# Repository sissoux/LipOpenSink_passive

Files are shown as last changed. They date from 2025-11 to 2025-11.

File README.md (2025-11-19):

# E-DDY

Smart passive load add-on for the ToolkitRC M8D charger. Bridges Channel 1 → Channel 2 into an external 3.3 Ω / 300 W resistor for higher discharge power. An onboard RP2040 supervises temperature, drives a 12 V fan (from the M8D’s USB-C PD), and cuts the load on error/thresholds. A simple USB configuration tool lets you tune behavior and monitor telemetry.

> Safety note: Ensure adequate cooling. Firmware enforces "no fan → no load": when the fan tach (GP12) shows no pulses while the fan should be running, the load is forced OFF and the LED blinks. Temperature and VIN thresholds also protect the load.

---

## Features

- Temperature monitoring with configurable filtering and calibration
- Fan control via LUT (temperature → PWM duty) with hysteresis and smooth ramping
- Load cutoff on over-temperature, with LED indicator
- Optional VIN-based load cutoff with hysteresis (configurable)
- Fan presence check via tach on GP12; interlock enforces "no fan → no load" with blinking LED
- Broken temperature sensor safety: if NTC (high-side) reads unrealistically low (< -25°C), the load is opened
- Settings persistence in RP2040 NVM (CRC-checked, adaptive to capacity)
- USB configuration tool (CDC/serial) to edit parameters and view telemetry

---

## Repository structure

```text
.
├── firmware/               # RP2040 (CircuitPython)
│   ├── boot.py             # Optional: expose dual CDC ports early
│   ├── code.py             # Firmware entry point
│   ├── LUTs.py             # Lookup tables (ADC→Temp, Temp→Duty)
│   └── uart_cmd.py         # Dual-CDC + ASCII command server
│
├── config_tool/            # PC configuration utility (Python 3)
│   ├── config_gui.py       # Tkinter GUI: params, telemetry, calibration
│   └── requirements.txt    # Dependencies for the GUI
│
├── PCB/                    # Hardware design (Altium) + outputs
│   ├── SRC/                # Schematics, PCB project/files
│   ├── FAB/                # Gerbers, drill, fabrication outputs
│   ├── ASSY/               # BOM, pick-and-place
│   └── 3D/                 # STEP and 3D PDF
│
├── tools/                  # Host-side helpers
│   ├── Temperature Log Plotter.py  # Plot CSV telemetry (example)
│   └── reports/            # Example logs and plots
│
└── README.md
```

Note: Hardware CAD and 3D outputs are provided under the license below.

---

## Quick start

### Hardware

1. Assemble the module with the 3.3 Ω / 300 W resistor, fan, and RP2040 board.
2. Power the fan from the M8D USB-C (12 V PD) as designed in your hardware.
3. Wire the module in the M8D’s discharge bridge path (CH1 → resistor → CH2).

### Firmware (RP2040)

1. Install CircuitPython for your RP2040 board.
2. Copy `firmware/code.py` and `firmware/LUTs.py` to the CIRCUITPY drive.
	- Optional: also copy `firmware/boot.py` to expose both CDC endpoints on boot.
3. Power-cycle the board; defaults will run immediately (telemetry is OFF by default).
4. Optionally adjust settings with the configuration tool and save to NVM.

### Configuration tool (PC)

Install dependencies (Windows PowerShell example):

```
pip install -r config_tool/requirements.txt
```

Launch the GUI:

```
python config_tool/config_gui.py
```

In the GUI:

- Select the serial port (CDC/COM) and Auto-Connect or Connect.
- Use Refresh to load current parameters; adjust values and Apply; Save to flash when satisfied.
- Live telemetry (CSV mode) is shown in the panel; you can set manual fan duty for testing.
- Use Start Rec to log Temperature (°C) and fan duty (%) every 1 s; click Stop to choose where to save the CSV.

Currently, the GUI focuses on parameters, telemetry, and basic calibration. LUT editing (upload/download) is supported by the device’s ASCII protocol but not yet exposed in the GUI.

---

## What you can configure

- Thermal & safety: cutoff temperature, hysteresis, ADC filtering
- Fan behavior: minimum duty, ramp time/step, temperature → duty LUT (device-side)
- Calibration: VIN and temperature channels (a·x + b) — temperature offset/slope act on °C
- Telemetry: rate (ms) and format (CSV or human-readable)
- VIN-based load cutoff: `LOAD_TRIP_V` and `HYST_V`

---

## Updating LUTs (advanced)

LUTs can be retrieved and updated via the serial ASCII protocol implemented in `uart_cmd.py`:

- GET/SET LUT TEMP_TO_DUTY
- GET/SET LUT ADC_TO_TEMP_5C

Use a serial terminal to issue HELP for the exact command shapes (BEGIN/END block mode with indexed rows). GUI support for LUT editing is planned but not yet available.

---

## Typical workflow

1. Power the module from the M8D (USB-C 12 V) and flash the firmware.
2. Verify the fan ramps according to temperature requirements.
3. Connect the configuration tool; adjust calibration, thresholds, and telemetry rate.
4. Save to flash, run a controlled discharge, and iterate based on telemetry.

---

## License

Licensed under CERN-OHL-S-2.0

© 2025 ADSTech [e-ddy]

https://ohwr.org/licences/

---

## Versioning & Breaking Changes

The configuration GUI performs a firmware version check on connect. Minimum supported firmware: **v1.3.1**.

| Area | Change | Firmware Version | GUI Impact |
|---|---|---|---|
| Safety | Added broken sensor low-temp safety (`BROKEN_TEMP_CUTOFF_C`, opens load if temp < -25°C) | 1.3.1 | Automatically enforced; no GUI control |
| Voltage Policy | Independent VIN cutoff with hysteresis (`LOAD_TRIP_V`, `HYST_V`) | 1.3.1 | Editable in GUI |
| Voltage Policy | Added VIN cutoff bypass parameter `BYPASS_VIN_CUTOFF` (1=bypass enabled) | 1.3.1 | Checkbox in GUI; hidden/disabled if firmware < 1.3.1 |
| Telemetry | CSV telemetry expanded (includes load state, mode) | 1.3.1 | Parsed by GUI recorder |
| GUI Logging | 1 Hz recording of Temperature & Fan Duty to CSV | (host feature) | Available regardless of firmware (needs CSV telemetry enabled) |
| Fan Safety | Fan tach interlock & LED blink on fault | 1.3.1 | Enforced by firmware; no GUI control |

If the firmware version is below the minimum, the GUI will:
1. Show a warning dialog on connect.
2. Disable controls for parameters not supported by the older firmware (e.g., `BYPASS_VIN_CUTOFF`).
3. Skip applying unsupported parameters to avoid parse errors.

### Upgrading Firmware

1. Copy updated `code.py` (and optionally `boot.py`) to the `CIRCUITPY` drive.
2. Power-cycle the RP2040.
3. Reconnect with the GUI; ensure the status bar shows the new firmware version.

### Legacy Behavior (< 1.3.1)

- VIN cutoff bypass not available; VIN cutoff may behave differently (combined with temperature logic).
- Broken sensor protection absent (extremely low temps might not force load open).
- Fan tach/LED fault logic absent; load may remain enabled even if fan stalls.

## Notes

- Firmware v1.3.1 monitors a Power-Good input but does not gate the load from it; load enable is controlled by temperature and VIN thresholds.
- Set the ToolkitRC M8D to discharge/bridge as per its documentation.
- Validate thermal performance for your specific mechanical design and environment before full-power operation.

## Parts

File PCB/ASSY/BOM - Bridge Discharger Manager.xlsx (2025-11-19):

Bill of Materials |  |  |  |  |  |  | #VALUE!
Project : |  | Bridge Discharger Manager |  |  | Report DateTime : | 19/11/2025 10:50 | Licensed under CERN-OHL-S-2.0
Revision : |  | B |  |  |  |  | © 2025 ADSTech [e-ddy]
 |  |  |  |  |  |  | https://ohwr.org/licences/
 |  |  |  |  | Primary |  | LCSC Equivalent
Line # | Name | Designator | Quantity | Description | Manufacturer 1 | Manufacturer Part Number 1 | Supplier par number
 | C-0402-CER-X7R-100nF-10%-50V | C1, C5, C7, C8, C9, C10, C11, C13, C14, C15, C16, C17, C19, C23, C25 | 15 | Multilayer Ceramic Capacitor, 0.1 uF, 50 V, ± 10%, X7R, 0402 [1005 Metric] | Murata | GRM155R71H104KE14J | C2649519
 | C-0805-CER-X5R-22µF-25V | C3 | 1 | Ceramic Capacitor, Multilayer, Ceramic, 25V, 20% +Tol, 20% -Tol, X5R, 15% TC, 22uF, Surface Mount, 0805 | Murata | GRM21BR61E226ME44L | C86816
 | C-0805-CER-X7R-4,7µF-10%-50V | C4, C12 | 2 | Ceramic Capacitor, Multilayer, Ceramic, 50V, 10% +Tol, 10% -Tol, X7R, 15% TC, 4.7uF, Surface Mount, 0805 | Murata | GRM21BZ71H475KE15K | C3898967
 | C-1206-CER-X7R-1nF-10%-1kV | C6 | 1 | Ceramic Capacitor, Multilayer, Ceramic, 1000V, 10% +Tol, 10% -Tol, X7R, 15% TC, 0.001uF, Surface Mount, 1206 | Murata | GCJ31BR73A102KXJ1L | C440144
 | C-0402-CER-X5R-1µF-10%-25V | C18, C20 | 2 | Ceramic Capacitor, Multilayer, Ceramic, 25V, 10% +Tol, 10% -Tol, X5R, 15% TC, 1uF, Surface Mount, 0402 | Murata | GRM155R61E105KA12J | C77009
 | C-0402-C0G-22pF-50V-1% | C21, C22 | 2 | Multilayer Ceramic Capacitors MLCC - SMD/SMT 50V 22pF C0G 0402 +/-1% | Kyocera AVX | 04025A220FAT2A | C41361085
 | C-0402-C0G-100pF-50V-1% | C24 | 1 | Multilayer Ceramic Capacitors MLCC - SMD/SMT 50V 100pF C0G 0402 +/-1% | KYOCERA AVX | 04025A101FAT2A | C597012
 | D-ESD-USB-4 lines 3.6V | D1 | 1 | Trans Voltage Suppressor Diode, 17W, 3.6V V(RWM), Bidirectional, 4 Element, Silicon | Texas Instruments | TPD4E02B04DQAR | C106794
 | D-TVS-33V-TVS3300DRVR | D2, D4 | 2 | Trans Voltage Suppressor Diode, 33V V(RWM), Unidirectional, Silicon | Texas Instruments | TVS3300DRVR | C2863624
 | D-ZEN-12V-BZX84C12-7-F | D3 | 1 | Zener Diode, 12V V(Z), 5.39%, 0.35W, Silicon, Unidirectional | Diodes Inc. | BZX84C12-7-F | C85186
 | LED-Red-633nm-0603 | D5, D12 | 2 | Red 633nm 0603 LED | Dialight | 598-8010-107F | C2286
 | D-TVS-14V-TVS1400DRVR | D6 | 1 | Trans Voltage Suppressor Diode, 14V V(RWM), Unidirectional, Silicon | Texas Instruments | TVS1400DRVR | C1975229
 | ESD-0603ESDA-MLP1 | D7, D8, D9 | 3 | Suppressor Esd 0.05PF 0603 SMD | Cooper Bussmann | 0603ESDA-MLP1 | C328933
 | D-SCH-VSSAF5N50-DO-221AD-2-5A-50V | D10, D11 | 2 | Rectifier Diode, Schottky, 1 Phase, 1 Element, 5A, 50V V(RRM), Silicon, DO-221AC | Vishay | VSSAF5N50-M3/6B | C7389237
 | FUSE-HOLDER-Nanofuse | F1 | 1 | Fuses/Accessories | Littelfuse | 01550900M | C206921
 | CON-TERM-3-5.08-30/12AWG | J1 | 1 | Terminal Block, Wtb, 3POS, 30-12AWG; | Global Connector Technology | TBJ05-03-1-G-G | C72334
 | CON-USBC-RA-TH | J2 | 1 | USB Connector, 16 Contact(s), Female, Right Angle, Solder Terminal, Receptacle | Global Connector Technology | USB4085-GF-A | C7095263
 | 47053-1000 | J3 | 1 | CONN HEADER VERT 4POS 2.54MM | Molex | 47053-1000 | C240840
 | L-2424-22uH-2.1A-74404064220 | L1 | 1 | General Purpose Inductor, 22uH, 20%, 1 Element, SMD, 2424 | Wurth Elektronik | 74404064220 | C168080
 | IC-Optocoupler-VOM1271T | O1 | 1 | Buffer/Inverter Based MOSFET Driver, 0.000007A, PDSO4 | Vishay | VOM1271T | C146286
 | TR-MOSN-DPAK-60V-110A-IRFR7540PBF | Q1 | 1 | Power Field-Effect Transistor | Infineon | IRFR7540TRPBF | C94897
 | TR-MOSN-SOT23-60V-0.115A-2N7002 | Q2, Q3 | 2 | Small Signal Field-Effect Transistor, 0.115A I(D), 60V, 1-Element, N-Channel, Silicon, Metal-oxide Semiconductor FET | Diodes Inc. | 2N7002-7-F | C85049
 | R-0402-10000.0-1%-100ppm-0.5 | R1, R24, R25 | 3 | 0402 10000.0 Ω 1% 100ppm 0.063W Resistor | Yageo Group | RC0402FR-0710KL | C191123
 | R-0402-5110.0-1%-100ppm-0.5 | R2, R13 | 2 | 0402 5110.0 Ω 1% 100ppm 0.063W Resistor | Vishay | CRCW04025K11FKED | C2091561
 | R-0402-22100.0-1%-100ppm-0.5 | R3, R11 | 2 | 0402 22100.0 Ω 1% 100ppm 0.063W Resistor | Vishay | CRCW040222K1FKED | C844504
 | R-0603-10000.0-1%-100ppm-0.1 | R4, R5 | 2 | 0603 10000.0 Ω 1% 100ppm 0.1W Resistor | Vishay | CRCW060310K0FKED | C844918
 | R-0603-49900.0-1%-100ppm-0.1 | R6 | 1 | 0603 49900.0 Ω 1% 100ppm 0.1W Resistor | Vishay | CRCW060349K9FKEA | C844789
 | R-0603-178.0-1%-100ppm-0.1 | R7 | 1 | 0603 178.0 Ω 1% 100ppm 0.1W Resistor | Vishay | CRCW0603178RFKEA | C100815
 | R-0402-27.4-1%-100ppm-0.5 | R8, R9 | 2 | 0402 27.4 Ω 1% 100ppm 0.063W Resistor | Vishay | CRCW040227R4FKED | C31439
 | R-0402-499.0-1%-100ppm-0.5 | R10, R14 | 2 | 0402 499.0 Ω 1% 100ppm 0.063W Resistor | Vishay | CRCW0402499RFKED | C2076754
 | R-0402-69800.0-0.1%-25ppm-0.016 | R12 | 1 | 0402 69800.0 Ω 0.1% 25ppm 0.016W Resistor | Yageo Group | RT0402BRD0769K8L | C852893
 | R-0402-1000.0-1%-100ppm-0.5 | R15, R16, R20 | 3 | 0402 1000.0 Ω 1% 100ppm 0.063W Resistor | Vishay | CRCW04021K00FKED | C71623
 | R-0402-5110.0-0.1%-25ppm-0.016 | R17 | 1 | 0402 5110.0 Ω 0.1% 25ppm 0.016W Resistor | Panasonic | ERA-2AEB5111X | C705788
 | NTC-0603-10k-3428K | R18 | 1 | NTC Thermistor, 10000ohm, Surface Mount | Murata | NCU18XH103F6SRB | C162670
 | R-0402-49900.0-0.1%-25ppm-0.016 | R19 | 1 | 0402 49900.0 Ω 0.1% 25ppm 0.016W Resistor | Yageo Group | RT0402BRD0749K9L | C852808
 | R-0402-2000.0-1%-100ppm-0.5 | R21 | 1 | 0402 2000.0 Ω 1% 100ppm 0.063W Resistor | Vishay | CRCW04022K00FKED | C482125
 | R-0402-121.0-1%-100ppm-0.5 | R22 | 1 | 0402 121.0 Ω 1% 100ppm 0.063W Resistor | Vishay | CRCW0402121RFKED | C25080
 | R-0402-13000.0-1%-100ppm-0.5 | R23 | 1 | 0402 13000.0 Ω 1% 100ppm 0.063W Resistor | Vishay | CRCW040213K0FKED | C25754
 | R-0402-90900.0-1%-100ppm-0.5 | R26 | 1 | 0402 90900.0 Ω 1% 100ppm 0.063W Resistor | Vishay | CRCW040290K9FKED | C2076677
 | BTN-3x2.5x1.2-12V-50mA | SW1 | 1 | Keypad Switch, 1 Switches, SPST, Momentary-tactile, 0.05A, 12VDC, 1.99N, Solder Terminal, Surface Mount-straight | Omron | B3U-1000P | C231329
 | IC-DCDC-POS-LMR51410 | U1 | 1 | SIMPLE SWITCHER® 4V to 42V, 1A synchronous buck converter with 26.5uA IQ 6-SOT-23 -40 to 150 | Texas Instruments | LMR51410YFDBVR | C35162557
 | IC-MCU-RP2040 | U3 | 1 | 264KB 30 133MHZ LQFN-56(7X7) Microcontrollers (mcu/mpu/soc) Rohs | Raspberry Pi | RP2040 | C2040
 | W25Q16JVZPIQ | U4 | 1 | IC FLASH 16MBIT SPI/QUAD 8WSON | Winbond | W25Q16JVZPIQ | C571260
 | XTAL-12MHz-20ppm | Y1 | 1 | Crystal 12MHz ±20ppm (Tol) ±50ppm (Stability) 18pF FUND 120Ohm 4-Pin Ultra Mini-CSMD T/R | Abracon | ABM8-12.000MHZ-B2-T | C6491123

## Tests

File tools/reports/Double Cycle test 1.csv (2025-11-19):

time_s | temp_c | fan_duty_pct
0.0 | 27.1 | 20.0
1.006133794784546 | 27.1 | 20.0
2.02009916305542 | 27.1 | 20.0
3.027132987976074 | 27.1 | 20.0
4.027637004852295 | 27.0 | 20.0
5.040283441543579 | 27.1 | 20.0
6.050336599349976 | 27.2 | 20.0
7.052570343017578 | 27.2 | 20.0
8.057480335235596 | 27.1 | 20.0
9.057487487792969 | 27.2 | 20.0
10.0596022605896 | 27.1 | 20.0
11.061896562576294 | 27.2 | 20.0
12.061650514602661 | 27.1 | 20.0
13.06770396232605 | 27.1 | 20.0
14.067284345626831 | 27.0 | 20.0
15.070570945739746 | 27.1 | 20.0
16.070485830307007 | 27.1 | 20.0
17.073445558547974 | 27.2 | 20.0
18.074161052703857 | 27.1 | 20.0
19.07569122314453 | 27.3 | 20.0
20.077850103378296 | 27.2 | 20.0
21.077765464782715 | 27.3 | 20.0
22.08387327194214 | 27.2 | 20.0
23.084920406341553 | 27.3 | 20.0
24.086239099502563 | 27.3 | 20.0
25.08726191520691 | 27.3 | 20.0
26.08731484413147 | 27.4 | 20.0
27.088814735412598 | 27.4 | 20.0
28.090100288391113 | 27.5 | 20.0
29.090941429138184 | 27.5 | 20.0
30.091214656829834 | 27.5 | 20.0
31.097475290298462 | 27.5 | 20.0
32.10014224052429 | 27.7 | 20.0
33.1007182598114 | 27.8 | 20.0
34.10033202171326 | 27.8 | 20.0
35.10492300987244 | 27.9 | 20.0
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

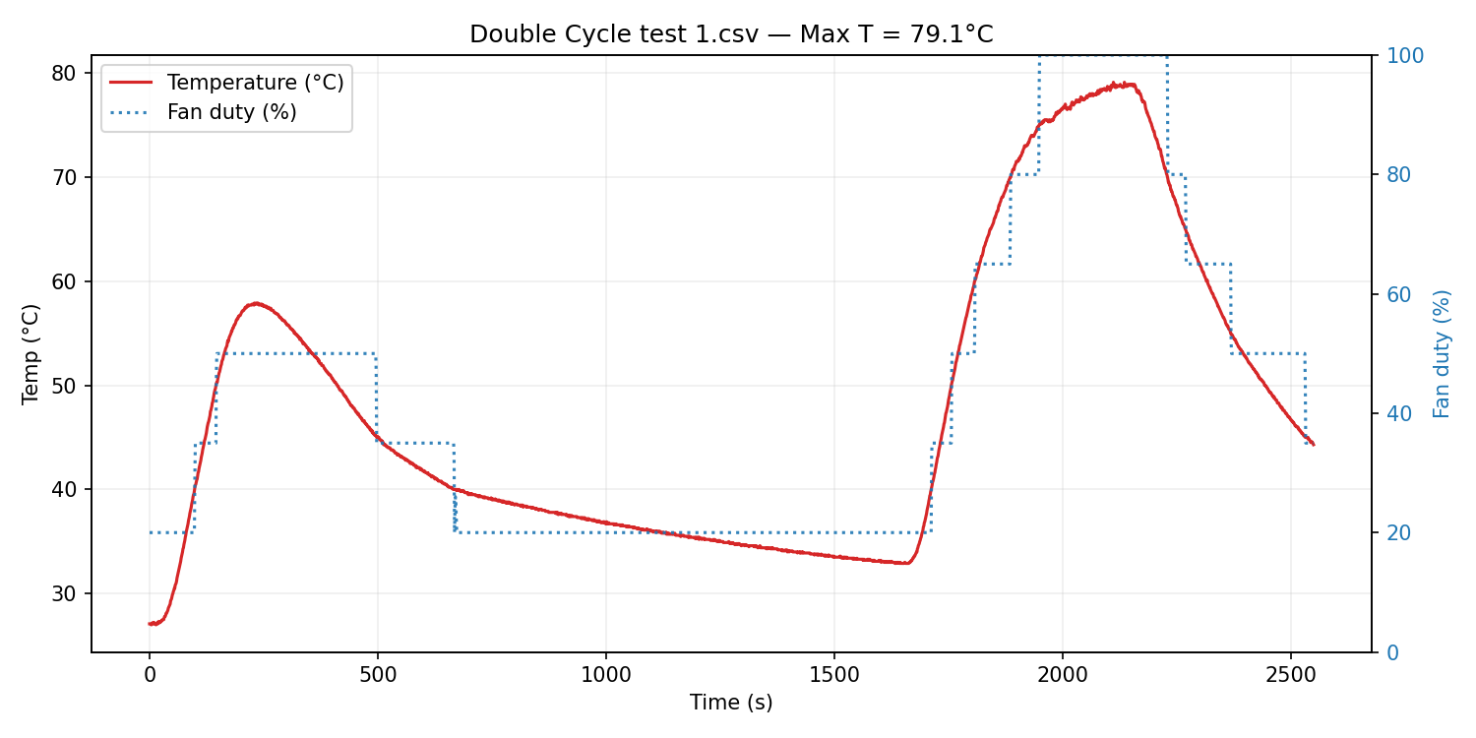
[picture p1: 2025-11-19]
tools/reports/Double Cycle test 1_plot.png

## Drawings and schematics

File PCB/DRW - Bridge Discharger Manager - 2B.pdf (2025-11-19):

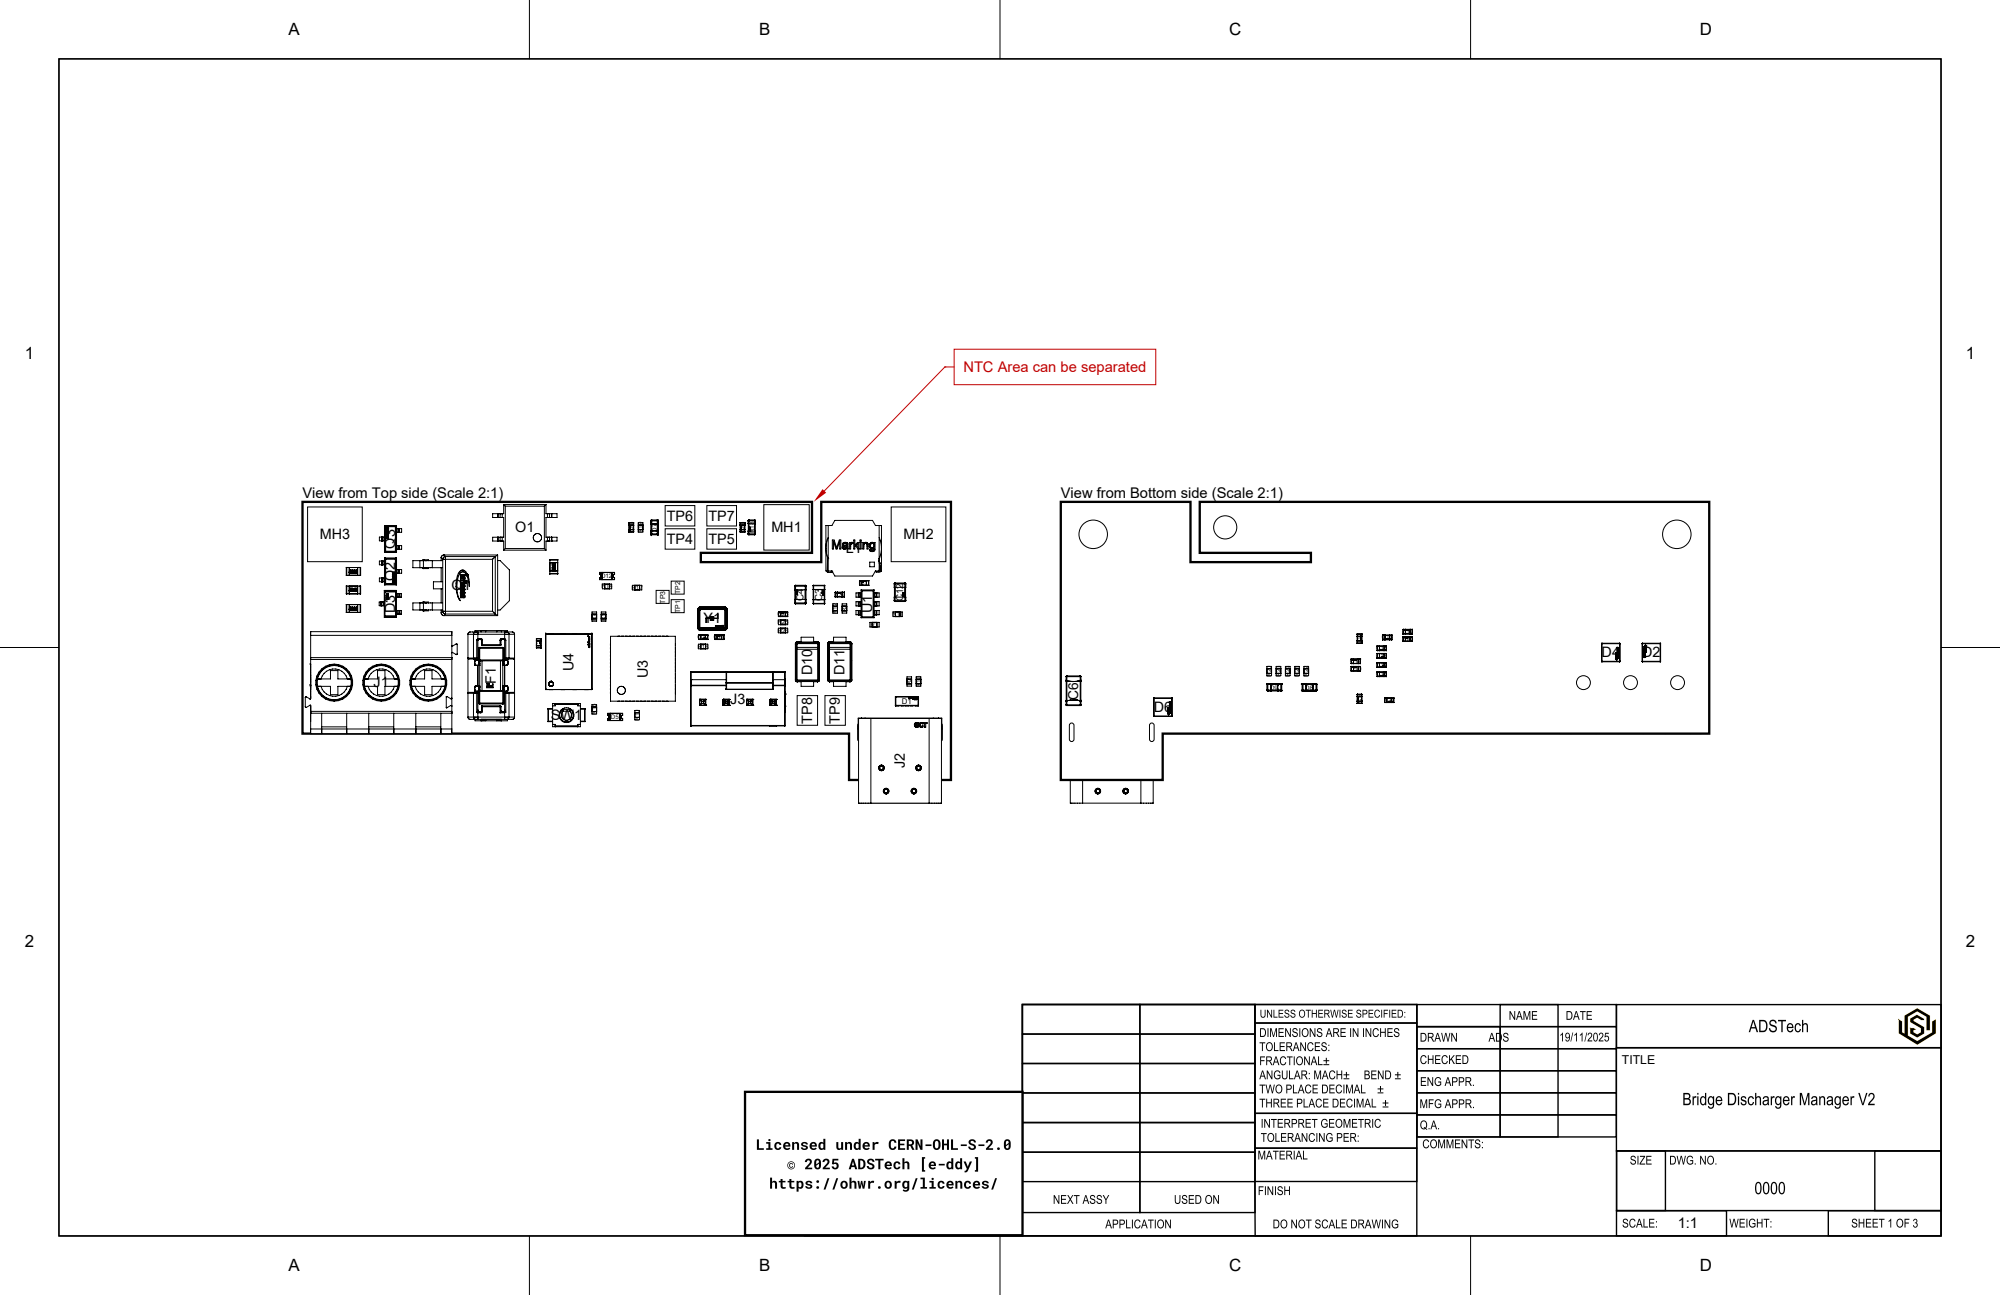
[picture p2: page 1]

NTC Area can be separated

View from Top side (Scale 2:1)

View from Bottom side (Scale 2:1)

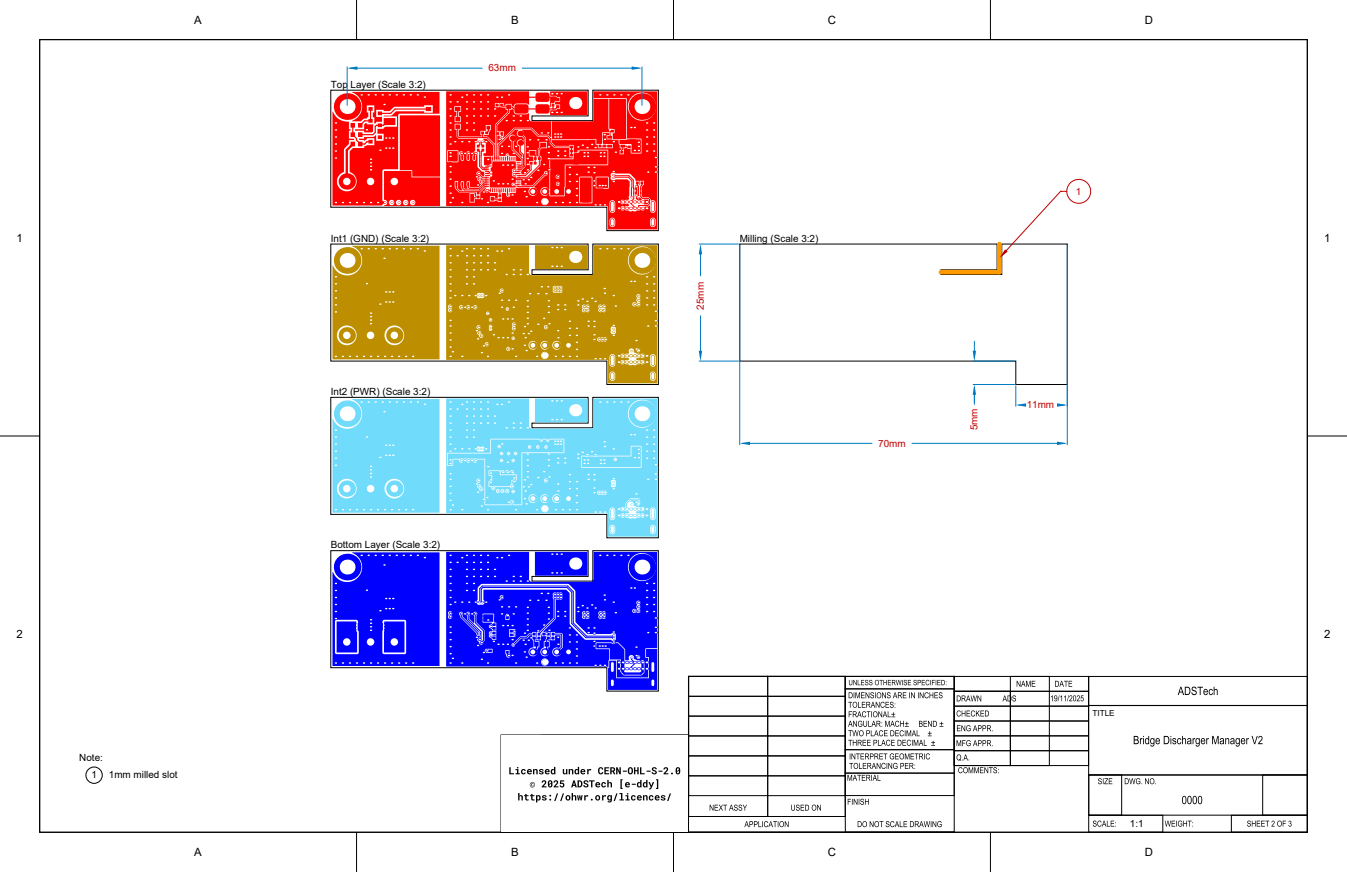
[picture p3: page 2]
Int1 (GND) (Scale 3:2); Int2 (PWR) (Scale 3:2); Milling (Scale 3:2); TITLE; 1 1mm milled slot; Note:

Top Layer (Scale 3:2)

Bottom Layer (Scale 3:2)

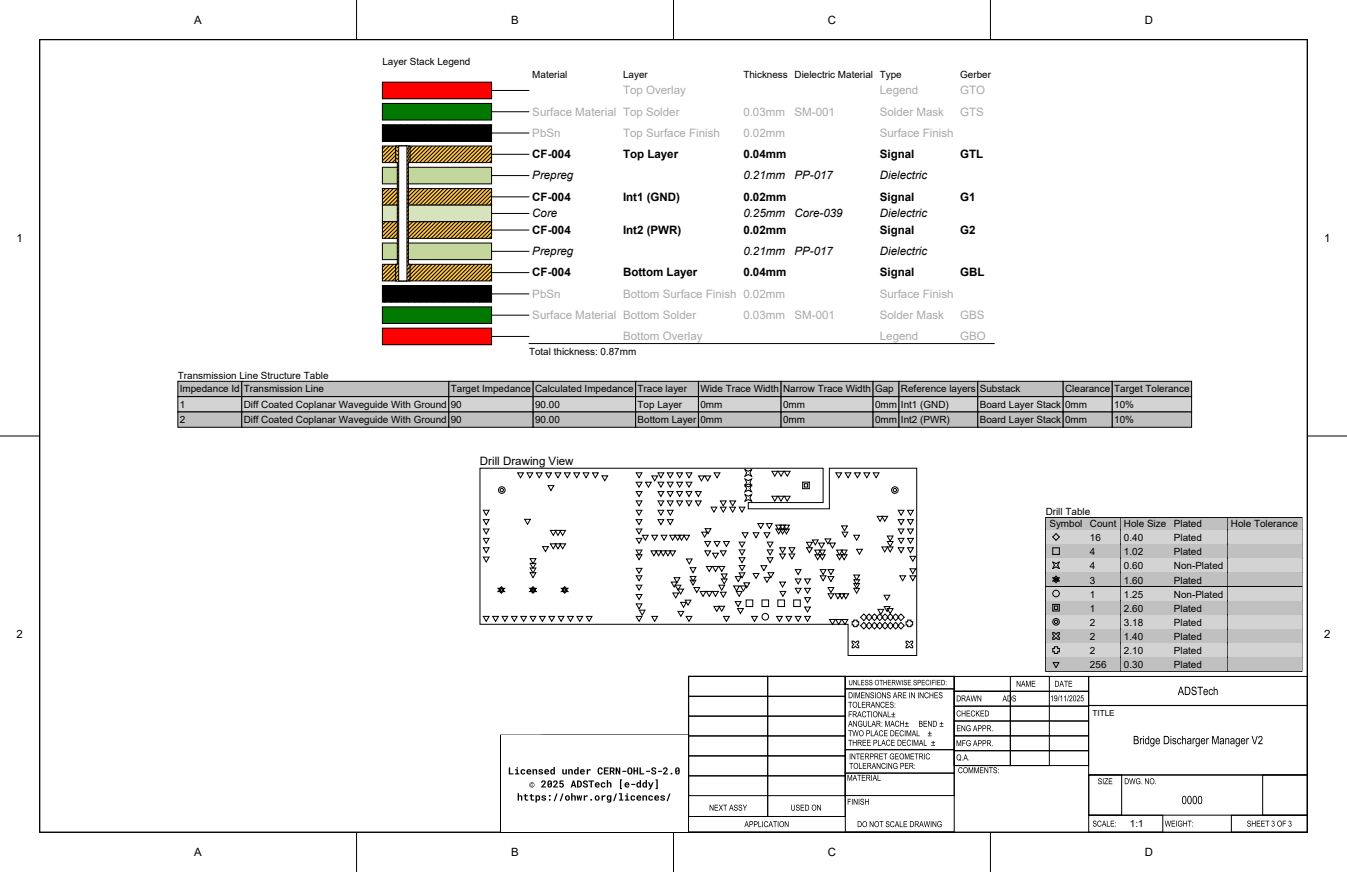
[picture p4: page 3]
TITLE; Drill Table; Material; Layer; Thickness Dielectric Material Type; Gerber; Top Overlay; Legend; GTO; Surface Material Top Solder; Solder Mask; GTS; PbSn; Top Surface Finish; Surface Finish; Top Layer; Signal; GTL; Prepreg; Dielectric; Int1 (GND); Core; 0.25mm Core-039; Int2 (PWR); Bottom Layer; GBL; Bottom Surface Finish 0.02mm; Surface Material Bottom Solder; GBS; Bottom Overlay; GBO; Total thickness: 0.87mm; Target Impedance 90 90; Calculated Impedance 90.00 90.00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

Layer Stack Legend

Transmission Line Structure Table
Impedance Id

Transmission Line
Diff Coated Coplanar Waveguide With Ground

Substack
Board Layer Stack

Drill Drawing View

Symbol | Count | Hole Size | Plated | Hole Tolerance

16 | 0.40 | Plated
4 | 1.02 | Plated
4 | 0.60 | Non-Plated
3 | 1.60 | Plated
1 | 1.25 | Non-Plated
1 | 2.60 | Plated
2 | 3.18 | Plated
2 | 1.40 | Plated
2 | 2.10 | Plated
256 | 0.30 | Plated

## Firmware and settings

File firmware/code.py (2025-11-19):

# Licensed under CERN-OHL-S-2.0
# © 2025 ADSTech [e-ddy]
# https://ohwr.org/licences/

"""
code.py — E-DDY main firmware (RP2040, CircuitPython).

Responsibilities:
- Hardware init (ADC, GPIO, PWM).
- Filtering (IIR), calibration (a*x+b), and temperature conversion (LUT).
- Fan policy with LUT + hysteresis + linear ramp; manual override support.
- Load cutoff with hysteresis; LED bonded to LOAD_EN.
- Telemetry generation (OFF by default).
- NVM-backed settings persistence with CRC and adaptive size.
- Integration with uart_cmd.CommandServer for UART protocol.

Requires:
- LUTs.py providing:
    - ADC_TO_TEMP_5C: list[(adc_count:int, temp_c:float)] sorted by decreasing adc
    - TEMP_TO_DUTY:   list[(temp_c:float, duty:float)]   sorted by increasing temp
- uart_cmd.py (this repo) for UART I/O and command parsing.

Optional:
- boot.py with `usb_cdc.enable(console=True, data=True)` to expose 2 CDC ports.

Author: E-DDY project
"""

import time
import math
import json
import struct
import microcontroller
import board
import analogio
import digitalio
import pwmio

from LUTs import ADC_TO_TEMP_5C as ADC_TO_TEMP_BOOT, TEMP_TO_DUTY as TEMP_TO_DUTY_BOOT
from uart_cmd import DualCDC, CommandServer

# -------------------------------
# Version / constants
# -------------------------------
FW_VERSION = "1.3.1"  # Bumped version: distinguishes builds with VIN bypass param & GUI sync improvements
VREF = 3.3
ADC_MAX = 65535
SETTINGS_PATH = "/settings.json"  # optional file fallback (read-only while mounted)
BROKEN_TEMP_CUTOFF_C = -25.0  # Safety: if measured temperature is below this, treat as broken NTC and open load

# -------------------------------
# Hardware setup
# -------------------------------
vinADC = analogio.AnalogIn(board.A0)   # GP26 ADC0 — input voltage sense
tempADC = analogio.AnalogIn(board.A1)  # GP27 ADC1 — temperature sense

psu_power_good = digitalio.DigitalInOut(board.GP6)  # PSU power good (pulled-up)
psu_power_good.direction = digitalio.Direction.INPUT
psu_power_good.pull = digitalio.Pull.UP

fan = pwmio.PWMOut(board.GP13, frequency=1000, duty_cycle=0)  # 1 kHz Fan PWM
# NEW: Fan tachometer input (external pull-up)
fan_tach = digitalio.DigitalInOut(board.GP12)
fan_tach.direction = digitalio.Direction.INPUT
load_en = digitalio.DigitalInOut(board.GP28)                   # Load enable
load_en.direction = digitalio.Direction.OUTPUT
led = digitalio.DigitalInOut(board.GP4)                        # LED bonded to LOAD_EN
led.direction = digitalio.Direction.OUTPUT

# -------------------------------
# Parameters (editable via UART)
# -------------------------------
params = {
    # Control / policy
    "HYST_C":        5.0,       # °C hysteresis for steps & cutoff re-enable
    "LOAD_TRIP_C":   85.0,      # °C cutoff threshold
    "MIN_FAN_DUTY":  0.20,      # duty (0..1) when below first temp threshold
    "FAST_DT_MS":    5,         # fast loop (ADC/filter/control)
    "SLOW_DT_MS":    250,       # reserved
    "FC_TEMP_HZ":    0.5,       # IIR cutoff for temperature (Hz)
    "FC_VIN_HZ":     0.5,       # IIR cutoff for Vin (Hz)
    "RAMP_TIME_MS":  1000,      # fan duty ramp duration
    "RAMP_STEP_MS":  50,        # fan duty ramp update period

    # Telemetry (OFF by default)
    "TELEM_RATE_MS": 0,         # 0 = off
    "TELEM_FORMAT":  "HUMAN",   # "CSV" or "HUMAN"

    # Calibration on volts: y = a*x + b
    "TEMP_CAL_A":    1.0,
    "TEMP_CAL_B":    0.0,
    "VIN_CAL_A":     (10.0/100.9),
    "VIN_CAL_B":     0.0,

    # Added parameters for load cutoff on voltage
    "LOAD_TRIP_V":   8.5,       # Voltage cutoff threshold (V)
    "HYST_V":        0.5,       # Voltage hysteresis (V)
    # Bypass VIN cutoff (1.0 = bypass enabled, 0.0 = enforce VIN cutoff). When bypassed, only temperature governs cutoff.
    "BYPASS_VIN_CUTOFF": 1.0,

    # NEW: Fan presence checking / LED blink
    "FAN_CHECK_MIN_DUTY": 0.30,   # Only check tach when commanded duty >= this
    "FAN_SPINUP_MS":     1500,    # Grace after starting fan before checking
    "FAN_TACH_TIMEOUT_MS": 600,   # Fault if no edge seen within this window
    "LED_BLINK_MS":       300,    # Blink period when in fan-fault
}

# -------------------------------
# LUTs (editable via UART)
# -------------------------------
TEMP_TO_DUTY = [(float(t), float(d)) for (t, d) in TEMP_TO_DUTY_BOOT]
TEMP_TO_DUTY.sort(key=lambda x: x[0])
ADC_TO_TEMP_5C = [(int(a), float(t)) for (a, t) in ADC_TO_TEMP_BOOT]
ADC_TO_TEMP_5C.sort(key=lambda x: -x[0])  # descending adc

# -------------------------------
# State variables
# -------------------------------
# Filters (start at raw readings)
raw_vin_f = vinADC.value
raw_temp_f = tempADC.value
last_fast_ns = time.monotonic_ns()

# Fan & load states
lut_index = 0
load_enabled = True
base_load_enabled = True  # NEW: temp/VIN policy before fan interlock
fan_fault = False         # NEW: fan fault flag
temp_fault_low = False    # NEW: broken sensor safety (NTC open → very low apparent temp)

# Fan ramp
duty_target = 0.0
duty_cmd = 0.0
ramp_start_duty = 0.0
ramp_target = 0.0
ramp_start_ms = 0
last_ramp_ms = 0
fan_manual = False  # set true by FAN DUTY; unset by FAN AUTO

# Telemetry
last_telem_ms = 0

# NEW: Fan tach / LED blink state
last_tach_val = False
last_tach_edge_ms = 0
fan_spin_request_ms = 0
last_led_blink_ms = 0
led_blink_state = False

# -------------------------------
# Utility functions
# -------------------------------
def temp_steps():
    """Return the list of temperature thresholds (°C) from TEMP_TO_DUTY."""
    return [t for (t, _) in TEMP_TO_DUTY]


def duties():
    """Return the list of duty values (0..1) from TEMP_TO_DUTY."""
    return [d for (_, d) in TEMP_TO_DUTY]


def clamp(v, lo, hi):
    """Clamp value v within [lo, hi]."""
    if v < lo:
        return lo
    if v > hi:
        return hi
    return v


def iir_update(prev_y: float, x: float, fc_hz: float, dt_s: float) -> float:
    """
    First-order low-pass (exponential) with cutoff frequency fc_hz.

    Args:
        prev_y: previous filtered value.
        x: new raw sample.
        fc_hz: cutoff frequency (Hz); <=0 means passthrough.
        dt_s: sample interval in seconds.

    Returns:
        New filtered value.
    """
    if dt_s <= 0 or fc_hz <= 0:
        return x
    alpha = 1.0 - math.exp(-2.0 * math.pi * fc_hz * dt_s)
    if alpha < 0.0:
        alpha = 0.0
    if alpha > 1.0:
        alpha = 1.0
    return prev_y + alpha * (x - prev_y)

def calibrateTemp(rawTempValue: float) -> float:
    """
    Convert uncalibrated temperature in °C using the stored linear calibration.

    Args:
        rawTempValue: Temperature input (°C).

    Returns:
        Temperature in °C.
    """
    return params["TEMP_CAL_A"]*rawTempValue+params["TEMP_CAL_B"]

def temp_from_adc(raw_adc_count: int) -> float:
    """
    Convert ADC counts to °C using the 5°C LUT with linear interpolation.

    Args:
        raw_adc_count: ADC reading (0..65535).

    Returns:
        Temperature in °C.
    """
    if raw_adc_count >= ADC_TO_TEMP_5C[0][0]:
        return calibrateTemp(ADC_TO_TEMP_5C[0][1])
    if raw_adc_count <= ADC_TO_TEMP_5C[-1][0]:
        return calibrateTemp(ADC_TO_TEMP_5C[-1][1])
    for i in range(len(ADC_TO_TEMP_5C) - 1):
        a1, t1 = ADC_TO_TEMP_5C[i]
        a2, t2 = ADC_TO_TEMP_5C[i + 1]
        if a2 <= raw_adc_count <= a1:
            ratio = (raw_adc_count - a1) / (a2 - a1)
            return calibrateTemp(t1 + (t2 - t1) * ratio)
    return ADC_TO_TEMP_5C[-1][1]


def update_fan_policy(temp_c: float) -> None:
    """
    Update the current LUT index and target duty based on temperature
    with 5°C hysteresis between steps.

    Behavior:
      - Below first threshold → index 0 with MIN_FAN_DUTY.
      - Climb indices as temp crosses thresholds upwards.
      - Drop one index when temp falls by HYST_C below current threshold.
    """
    global lut_index, duty_target
    steps = temp_steps()
    n = len(steps)

    if temp_c < steps[0]:
        lut_index = 0
        duty_target = params["MIN_FAN_DUTY"]
        return

    while lut_index < n - 1 and temp_c >= steps[lut_index + 1]:
        lut_index += 1

    if lut_index > 0 and temp_c <= (steps[lut_index] - params["HYST_C"]):
        lut_index -= 1

    duty_target = duties()[lut_index]


def set_fan_target(new_target: float, now_ms: int) -> None:
    """
    Start a linear ramp towards the given target duty.

    Args:
        new_target: target duty in [0.0, 1.0].
        now_ms: monotonic time in milliseconds.
    """
    global ramp_start_duty, ramp_target, ramp_start_ms, duty_cmd, fan_spin_request_ms
    new_target = clamp(new_target, 0.0, 1.0)
    if new_target != ramp_target:
        ramp_start_duty = duty_cmd
        ramp_target = new_target
        ramp_start_ms = now_ms
    # NEW: Track spin request start for tach checking
    if new_target >= params["FAN_CHECK_MIN_DUTY"]:
        if fan_spin_request_ms == 0:
            fan_spin_request_ms = now_ms
    else:
        fan_spin_request_ms = 0


def service_fan_ramp(now_ms: int) -> None:
    """
    Update PWM duty along a linear ramp according to RAMP_TIME_MS and RAMP_STEP_MS.
    """
    global duty_cmd, last_ramp_ms
    if params["RAMP_TIME_MS"] <= 0:
        duty_cmd = ramp_target
    else:
        if now_ms - last_ramp_ms >= params["RAMP_STEP_MS"]:
            last_ramp_ms = now_ms
            elapsed = now_ms - ramp_start_ms
            if elapsed <= 0:
                duty_cmd = ramp_start_duty
            elif elapsed >= params["RAMP_TIME_MS"]:
                duty_cmd = ramp_target
            else:
                frac = elapsed / float(params["RAMP_TIME_MS"])
                duty_cmd = ramp_start_duty + frac * (ramp_target - ramp_start_duty)
    fan.duty_cycle = 0 if duty_cmd <= 0.0 else int(duty_cmd * 65535)


# -------------------------------
# NVM persistence (CRC-checked, adaptive)
# -------------------------------
_MAGIC = b"LOSP"  # E-DDY (kept as 'LOSP' for NVM backward compatibility)
_VER = 1  # settings schema version


def _crc16_ccitt(data, poly=0x1021, init=0xFFFF) -> int:
    """Return CRC-16/CCITT of the given bytes."""
    crc = init
    for b in data:
        crc ^= (b << 8)
        for _ in range(8):
            if crc & 0x8000:
                crc = ((crc << 1) ^ poly) & 0xFFFF
            else:
                crc = (crc << 1) & 0xFFFF
    return crc


def _nvm_capacity() -> int:
    """Return NVM capacity in bytes (0 if unavailable)."""
    try:
        return len(microcontroller.nvm)
    except Exception:
        return 0


def nvm_save(params_obj, td_lut, at_lut):
    """
    Persist settings into NVM; adapt content to available capacity.

    Tries (in order):
      1) params + TEMP_TO_DUTY + ADC_TO_TEMP_5C
      2) params + TEMP_TO_DUTY
      3) params only

    Returns:
        (ok: bool, info: str) describing what was saved or the reason of failure.
    """
    cap = _nvm_capacity()
    if cap <= 0:
        return False, "NVM_UNAVAILABLE"

    candidates = []
    candidates.append(
        (
            0x03,
            {
                "params": params_obj,
                "TEMP_TO_DUTY": [[float(t), float(d)] for (t, d) in td_lut],
                "ADC_TO_TEMP_5C": [[int(a), float(t)] for (a, t) in at_lut],
            },
        )
    )
    candidates.append(
        (
            0x01,
            {
                "params": params_obj,
                "TEMP_TO_DUTY": [[float(t), float(d)] for (t, d) in td_lut],
            },
        )
    )
    candidates.append((0x00, {"params": params_obj}))

    for flags, obj in candidates:
        payload = json.dumps(obj, separators=(",", ":")).encode("utf-8")
        header_wo_crc = _MAGIC + bytes([_VER, flags]) + struct.pack(">H", len(payload))
        crc = _crc16_ccitt(payload)
        blob = header_wo_crc + struct.pack(">H", crc) + payload
        if len(blob) <= cap:
            buf = bytearray(cap)  # clear remainder
            buf[: len(blob)] = blob
            microcontroller.nvm[:] = buf
            if flags == 0x03:
                return True, "NVM_SAVED_ALL"
            if flags == 0x01:
                return True, "NVM_SAVED_PARAMS_TD"
            return True, "NVM_SAVED_PARAMS"
    return False, "NVM_TOO_SMALL"


def nvm_load():
    """
    Load settings from NVM if valid.

    Returns:
        dict with keys among {"params","TEMP_TO_DUTY","ADC_TO_TEMP_5C"} or None if missing/invalid.
    """
    cap = _nvm_capacity()
    if cap <= 8:
        return None
    mem = bytes(microcontroller.nvm[:])
    if mem[:4] != _MAGIC:
        return None
    ver = mem[4]
    flags = mem[5]
    ln = struct.unpack_from(">H", mem, 6)[0]
    if 8 + ln > len(mem):
        return None
    crc_stored = struct.unpack_from(">H", mem, 8)[0]
    payload = mem[10 : 10 + ln]
    if _crc16_ccitt(payload) != crc_stored:
        return None
    try:
        data = json.loads(payload.decode("utf-8"))
    except Exception:
        return None
    if not isinstance(data, dict):
        return None
    return data


def load_settings_from_any() -> bool:
    """
    Load settings from NVM first; fallback to SETTINGS_PATH if present.

    Returns:
        True on success; False if nothing could be loaded (defaults remain).
    """
    data = nvm_load()
    if data is None:
        try:
            with open(SETTINGS_PATH, "r") as f:
                data = json.load(f)
        except Exception:
            return False
    try:
        if "params" in data:
            for k, v in data["params"].items():
                if k in params:
                    params[k] = v
        if "TEMP_TO_DUTY" in data:
            TEMP_TO_DUTY[:] = [(float(t), float(d)) for (t, d) in data["TEMP_TO_DUTY"]]
            TEMP_TO_DUTY.sort(key=lambda x: x[0])
        if "ADC_TO_TEMP_5C" in data:
            ADC_TO_TEMP_5C[:] = [(int(a), float(t)) for (a, t) in data["ADC_TO_TEMP_5C"]]
            ADC_TO_TEMP_5C.sort(key=lambda x: -x[0])
        return True
    except Exception:
        return False


def save_settings_any():
    """
    Persist settings to NVM only (robust while USB mass-storage is mounted).

    Returns:
        (ok: bool, info: str)
    """
    return nvm_save(params, TEMP_TO_DUTY, ADC_TO_TEMP_5C)


def load_defaults_ram():
    """Restore default parameters and boot LUTs."""
    params.update(
        {
            "HYST_C": 5.0,
            "LOAD_TRIP_C": 85.0,
            "MIN_FAN_DUTY": 0.20,
            "FAST_DT_MS": 5,
            "SLOW_DT_MS": 250,
            "FC_TEMP_HZ": 0.5,
            "FC_VIN_HZ": 0.5,
            "RAMP_TIME_MS": 1000,
            "RAMP_STEP_MS": 50,
            "TELEM_RATE_MS": 0,  # OFF by default
            "TELEM_FORMAT": "HUMAN",
            "TEMP_CAL_A": 1.0,
            "TEMP_CAL_B": 0.0,
            "VIN_CAL_A": (10.0 / 100.9),
            "VIN_CAL_B": 0.0,
            "LOAD_TRIP_V": 8.5,   # Default voltage cutoff
            "HYST_V": 0.5,        # Default voltage hysteresis
            "BYPASS_VIN_CUTOFF": 1.0,  # Default: bypass VIN cutoff enabled
            # NEW advanced (not exposed in GUI by default)
            "FAN_CHECK_MIN_DUTY": 0.30,
            "FAN_SPINUP_MS":     1500,
            "FAN_TACH_TIMEOUT_MS": 600,
            "LED_BLINK_MS":       300,
        }
    )
    TEMP_TO_DUTY[:] = [(float(t), float(d)) for (t, d) in TEMP_TO_DUTY_BOOT]
    TEMP_TO_DUTY.sort(key=lambda x: x[0])
    ADC_TO_TEMP_5C[:] = [(int(a), float(t)) for (a, t) in ADC_TO_TEMP_BOOT]
    ADC_TO_TEMP_5C.sort(key=lambda x: -x[0])


# -------------------------------
# Backend glue for CommandServer
# -------------------------------
class Backend:
    """Adapter exposing firmware state/methods to the CommandServer."""

    def __init__(self, io: DualCDC) -> None:
        self.io = io

    # --- Introspection ---
    def version(self) -> str:
        """Return firmware version string for VER?."""
        return FW_VERSION

    def status(self) -> dict:
        """Return connection status for STATUS?."""
        return self.io.endpoints_connected()

    # --- Parameters ---
    def get_params(self):
        """Return parameters as KEY=VALUE lines for GET PARAMS."""
        lines = []
        keys = [
            "MIN_FAN_DUTY",
            "HYST_C",
            "LOAD_TRIP_C",
            # Also include voltage cutoff parameters so GUI stays in sync
            "LOAD_TRIP_V",
            "HYST_V",
            "BYPASS_VIN_CUTOFF",
            "FAST_DT_MS",
            "SLOW_DT_MS",
            "FC_TEMP_HZ",
            "FC_VIN_HZ",
            "RAMP_TIME_MS",
            "RAMP_STEP_MS",
            "TELEM_RATE_MS",
            "TELEM_FORMAT",
            "TEMP_CAL_A",
            "TEMP_CAL_B",
            "VIN_CAL_A",
            "VIN_CAL_B",
            # NEW advanced (not exposed in GUI by default)
            "FAN_CHECK_MIN_DUTY",
            "FAN_SPINUP_MS",
            "FAN_TACH_TIMEOUT_MS",
            "LED_BLINK_MS",
        ]
        for k in keys:
            lines.append("{}={}".format(k, params[k]))
        return lines

    def set_param(self, key: str, value: str) -> None:
        """Set a parameter from text (type inferred by key)."""
        if key not in params:
            raise KeyError("UNKNOWN_KEY")
        if key in ("FAST_DT_MS", "SLOW_DT_MS", "RAMP_TIME_MS", "RAMP_STEP_MS", "TELEM_RATE_MS",
                   "FAN_SPINUP_MS", "FAN_TACH_TIMEOUT_MS", "LED_BLINK_MS"):
            params[key] = int(float(value))
        elif key == "TELEM_FORMAT":
            v = value.strip().upper()
            if v not in ("CSV", "HUMAN"):
                raise ValueError("BAD_FORMAT")
            params[key] = v
        else:
            params[key] = float(value)

    # --- LUTs ---
    def get_lut_temp_to_duty(self):
        """Return a copy of TEMP_TO_DUTY for GET LUT TEMP_TO_DUTY."""
        return list(TEMP_TO_DUTY)

    def set_lut_temp_to_duty(self, rows):
        """Install a new TEMP_TO_DUTY LUT from rows[(temp,duty), ...]."""
        rows = [(float(t), float(d)) for (t, d) in rows]
        rows.sort(key=lambda x: x[0])
        if not rows:
            raise ValueError("EMPTY")
        TEMP_TO_DUTY[:] = rows

    def get_lut_adc_to_temp(self):
        """Return a copy of ADC_TO_TEMP_5C for GET LUT ADC_TO_TEMP_5C."""
        return list(ADC_TO_TEMP_5C)

    def set_lut_adc_to_temp(self, rows):
        """Install a new ADC_TO_TEMP_5C LUT from rows[(adc,temp), ...]."""
        rows = [(int(a), float(t)) for (a, t) in rows]
        rows.sort(key=lambda x: -x[0])
        if not rows:
            raise ValueError("EMPTY")
        ADC_TO_TEMP_5C[:] = rows

    # --- Fan / Telemetry / Persistence ---
    def fan_auto(self) -> None:
        """Return fan control to AUTO policy mode."""
        global fan_manual
        fan_manual = False

    def fan_duty(self, d: float) -> None:
        """Set manual fan target duty (ramps)."""
        global fan_manual, ramp_target, ramp_start_duty, ramp_start_ms, duty_cmd, fan_spin_request_ms
        fan_manual = True
        now = now_ms()
        d = clamp(d, 0.0, 1.0)
        ramp_start_duty = duty_cmd
        ramp_target = d
        ramp_start_ms = now
        # NEW: start spin request if above threshold
        fan_spin_request_ms = now if d >= params["FAN_CHECK_MIN_DUTY"] else 0

    def telem_rate(self, ms: int) -> None:
        """Set telemetry period in ms (0 = off)."""
        params["TELEM_RATE_MS"] = max(0, int(ms))

    def telem_format(self, fmt: str) -> None:
        """Set telemetry format ('CSV' or 'HUMAN')."""
        fmt = fmt.strip().upper()
        if fmt not in ("CSV", "HUMAN"):
            raise ValueError("BAD_FORMAT")
        params["TELEM_FORMAT"] = fmt

    def save_settings(self):
        """Persist settings to NVM."""
        return save_settings_any()

    def load_defaults(self) -> None:
        """Restore defaults in RAM."""
        load_defaults_ram()

    def reboot(self) -> None:
        """Soft reset the microcontroller."""
        import time as _t
        import microcontroller as _m
        _t.sleep(0.1)
        _m.reset()


# -------------------------------
# Boot: load settings (NVM first)
# -------------------------------
load_settings_from_any()

# -------------------------------
# Timers & helpers
# -------------------------------
def now_ms() -> int:
    """Return monotonic time in milliseconds."""
    return time.monotonic_ns() // 1_000_000


t_fast = now_ms()
last_telem_ms = t_fast
last_ramp_ms = t_fast
ramp_start_ms = t_fast
last_temp_c = 25.0
# NEW: initialize tach/blink timers
last_tach_edge_ms = t_fast
last_led_blink_ms = t_fast
last_tach_val = fan_tach.value

# -------------------------------
# Startup LED version blink
# -------------------------------
def _blink_n(n: int, on_ms: int = 150, off_ms: int = 150) -> None:
    try:
        n = int(n)
    except Exception:
        n = 0
    if n <= 0:
        return
    for i in range(n):
        led.value = True
        time.sleep(on_ms / 1000.0)
        led.value = False
        if i != n - 1:
            time.sleep(off_ms / 1000.0)


def _parse_major_minor(vs: str) -> tuple:
    major = 0
    minor = 0
    try:
        tokens = vs.replace("-", ".").split(".")
        for tok in tokens:
            try:
                val = int(tok)
            except Exception:
                continue
            if major == 0:
                major = val
            elif minor == 0:
                minor = val
                break
    except Exception:
        pass
    return major, minor


def blink_version() -> None:
    maj, minr = _parse_major_minor(FW_VERSION)
    _blink_n(maj)
    time.sleep(1.0)
    _blink_n(minr)
    time.sleep(0.2)
    led.value = False

# Perform version blink at startup (non-blocking thereafter)
blink_version()

# -------------------------------
# UART server
# -------------------------------
io = DualCDC()
server = CommandServer(io, Backend(io))
io.write_line("READY E-DDY (FW {})".format(FW_VERSION))
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

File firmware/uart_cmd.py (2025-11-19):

# Licensed under CERN-OHL-S-2.0
# © 2025 ADSTech [e-ddy]
# https://ohwr.org/licences/

"""
uart_cmd.py — Dual-CDC UART + command server for E-DDY.

This module abstracts USB CDC I/O (console + data) and implements a small,
line-oriented ASCII protocol with a set of built-in commands. Application logic
(params, LUTs, telemetry control, persistence, etc.) is provided via a backend
object passed to `CommandServer`.

Key features:
- Reads from BOTH usb_cdc.console and usb_cdc.data (if available).
- Accepts CR, LF, or CRLF as line terminators.
- Writes responses to both ports using CRLF (avoids "stair-stepping").
- Minimal command parser with BEGIN/END block mode for LUT uploads.
- Helpers to write OK/ERR with optional payload and END.

Application must provide a backend object with the following callables:
- version() -> str
- status() -> dict[str, bool]                 # e.g., {"console": True, "data": True}
- get_params() -> list[str]                   # ["KEY=VALUE", ...]
- set_param(key: str, value: str) -> None
- get_lut_temp_to_duty() -> list[tuple[float,float]]
- set_lut_temp_to_duty(rows: list[tuple[float,float]]) -> None
- get_lut_adc_to_temp() -> list[tuple[int,float]]
- set_lut_adc_to_temp(rows: list[tuple[int,float]]) -> None
- fan_auto() -> None
- fan_duty(d: float) -> None
- telem_rate(ms: int) -> None
- telem_format(fmt: str) -> None              # "CSV" or "HUMAN"
- save_settings() -> tuple[bool, str]         # (ok, info)
- load_defaults() -> None
- reboot() -> None

The server will call these and handle I/O formatting.
"""

try:
    import usb_cdc
    try:
        # harmless if already enabled (e.g., via boot.py)
        usb_cdc.enable(console=True, data=True)
    except Exception:
        pass
except Exception:
    usb_cdc = None


class DualCDC:
    """Minimal dual-CDC UART abstraction with CRLF transmit and CR/LF tolerant RX."""

    def __init__(self) -> None:
        self.buf = bytearray()
        self.console = getattr(usb_cdc, "console", None) if usb_cdc else None
        self.data = getattr(usb_cdc, "data", None) if usb_cdc else None

    def read_into_buffer(self) -> None:
        """Drain available bytes from both CDC endpoints into the internal buffer."""
        if self.console and self.console.in_waiting:
            try:
                self.buf += self.console.read(self.console.in_waiting)
            except Exception:
                pass
        if self.data and self.data.in_waiting:
            try:
                self.buf += self.data.read(self.data.in_waiting)
            except Exception:
                pass

    def readline(self):
        """Return a decoded line (str) if a CR or LF is found, else None."""
        self.read_into_buffer()
        if not self.buf:
            return None
        cr = self.buf.find(b"\r")
        lf = self.buf.find(b"\n")
        idx = -1
        if cr != -1 and lf != -1:
            idx = cr if cr < lf else lf
        elif cr != -1:
            idx = cr
        elif lf != -1:
            idx = lf
        if idx == -1:
            return None
        line = self.buf[:idx]
        drop = 1
        if idx + 1 < len(self.buf) and self.buf[idx + 1:idx + 2] in (b"\r", b"\n"):
            drop = 2
        self.buf = self.buf[idx + drop :]
        try:
            return line.decode("utf-8", "replace")
        except Exception:
            return None

    def write_line(self, s: str) -> None:
        """Write a single line with CRLF. Broadcast to both endpoints; fallback to print()."""
        payload = (s + "\r\n").encode("utf-8")
        wrote = False
        if self.data:
            try:
                self.data.write(payload)
                wrote = True
            except Exception:
                pass
        if self.console:
            try:
                self.console.write(payload)
                wrote = True
            except Exception:
                pass
        if not wrote:
            # As a last resort, mirror to print so something is visible on REPL.
            print(s)

    def endpoints_connected(self) -> dict:
        """Return connection status for console and data endpoints."""
        return {
            "console": getattr(getattr(usb_cdc, "console", None), "connected", False),
            "data": getattr(getattr(usb_cdc, "data", None), "connected", False),
        }


class CommandServer:
    """
    Line-based command server.

    Parses ASCII commands terminated by CR/LF, calls backend methods, and writes
    OK/ERR responses. Supports block mode for LUT uploads:

    - SET LUT TEMP_TO_DUTY BEGIN <count>
      <idx,temp,duty>
      ...
      SET LUT TEMP_TO_DUTY END

    - SET LUT ADC_TO_TEMP_5C BEGIN <count>
      <idx,adc,temp>
      ...
      SET LUT ADC_TO_TEMP_5C END
    """

    def __init__(self, io: DualCDC, backend) -> None:
        """
        Args:
            io: DualCDC instance for I/O.
            backend: application backend with the required methods (see module docstring).
        """
        self.io = io
        self.backend = backend
        # block mode state
        self.rx_mode = None            # "TD" | "AT" | None
        self.rx_count_expected = 0
        self.rx_rows = []

    # ---------- helpers ----------
    def ok(self, lines=None, end=False):
        """Write OK; optional payload lines; optional END terminator."""
        self.io.write_line("OK")
        if lines:
            for s in lines:
                self.io.write_line(s)
        if end:
            self.io.write_line("END")

    def err(self, code: int, msg: str, end=False):
        """Write an error line. Example: ERR 400 PARSE"""
        self.io.write_line("ERR {} {}".format(code, msg))
        if end:
            self.io.write_line("END")

    # ---------- API ----------
    def poll(self) -> None:
        """Process at most one incoming line (non-blocking)."""
        line = self.io.readline()
        if line is None:
            return
        self._handle_line(line.strip())

    # ---------- internal ----------
    def _handle_line(self, s: str) -> None:
        if not s:
            return
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

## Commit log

2025-08-29 Temp and voltage calibration are workign now.
2025-08-29 Working calibration
2025-08-29 Corrected A Coef for VIn
    [config_gui.py]
2025-09-01 Added input voltage validation to load EN (not tested)
2025-09-01 Added Voltage trip parameters to the GUI
2025-11-05 Enhance fan control and monitoring features: - Update fan PWM thresholds for improved performance. - Implement fan tachometer input for presence checking. - Add parameters for fan spin-up timing and 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
2025-11-15 Add script to plot temperature and fan duty from CSV data
    - Implemented `load_csv` function to read and validate CSV files.
    - Created `simple_plot` function to generate a temperature vs. time plot.
    - Added support for optional fan duty percentage plotting on a secondary axis.
    - Included command-line argument parsing for file input and save options.
    - Output plot saved as PNG with max temperature printed to console.
    [Double Cycle test 1.csv]
2025-11-19 Add startup LED version blink functionality
2025-11-19 Add Double Cycle Test 1 plot image to reports
    [BOM - Bridge Discharger Manager.xlsx, Block diagram.SchDoc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]
2025-11-19 Rename project references from LipOpenSink_Passive to E-DDY across documentation and firmware files.
